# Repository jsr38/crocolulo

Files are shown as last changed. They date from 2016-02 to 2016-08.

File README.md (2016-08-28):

# crocolulo
Alligator Board expansion for >= 3A stepper motors

This repository contains hardware designs for an Alligator expansion board that replaces the Piggy.

My CoreXY 3D printer [savagecorexy](https://github.com/jsr38/savagecorexy) is currently fitted with Alligator Board electronics.  This expansion board allows an Alligator Board to neatly interface with 6 external high current stepper drivers as well as bring out analogue IO pins to a header for experimentation or further customisation.

crocolulo:
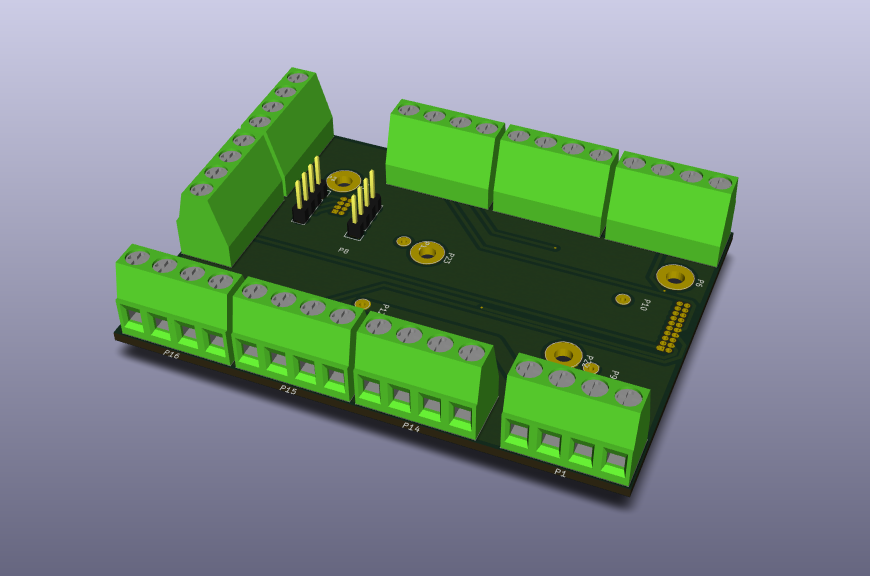
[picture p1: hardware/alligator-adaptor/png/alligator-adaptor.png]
Crocolulo Alligator Expansion


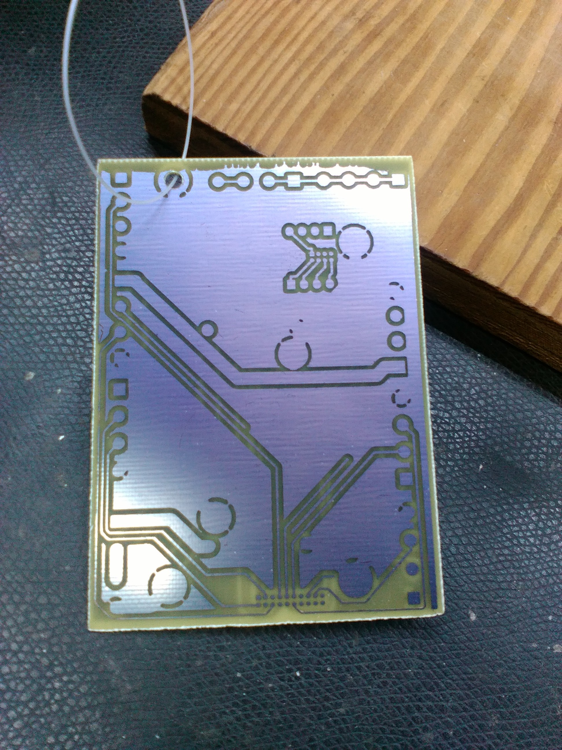
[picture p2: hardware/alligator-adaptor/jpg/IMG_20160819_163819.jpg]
One side of prototype PCB


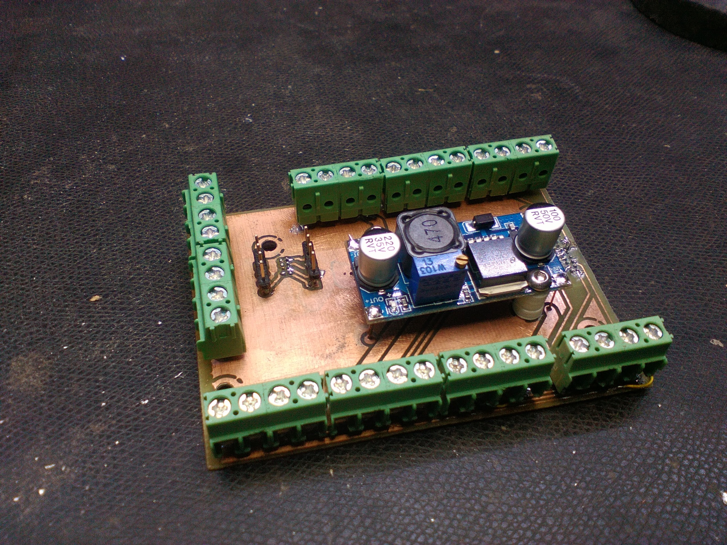
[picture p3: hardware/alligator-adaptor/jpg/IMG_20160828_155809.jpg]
Prototype version 0.1


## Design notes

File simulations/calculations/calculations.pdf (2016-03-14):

# 3D printer calculations

### Jeremy Reeve

Independent Researcher,
jeremy.reeve81@gmail.com

### March 14, 2016

## 1 Belt calculations

For an endless belt, what is the circumference required to fit two pullies, radii r1, r2 and separation, d?

l = π (r1 + r2) + 2q
s

2 + (r2 − r1)

2
(1)

Steps per millimeter of travel in the X direction:

## 2 Stepper motor calculations

Step frequency for 200 mms

−1
: 200 steps / 72mm pulley circumference step frequency 200 * 200 / 72 = 555.56 steps s

−1

1
f = 1.8ms
Waveform rise and fall times were taken from the IR2184 MOSFET High and Low Side driver datasheet.
For our gate drivers, per winding of the stepper this means one complete four state cycle per 1.8ms. As can be seen from plots of i(L1), we are only maximally inducing a current of 0.5A to flow, which means we have factor 2.8/0.5 = 5.6 less torque even at maximum current!!
Try with a slower rate 100mms⁻¹
As can be seen, with a 50% duty cycle, to allow for the other phase of the stepper winding, this is still less than 1.0A which is 1/3 of the rated torque. All the current waveforms seem to exhibit a bias toward -ve which increases with pulse length. Note that if the waveforms are reversed in time, reversing the order of the pulses, the -ve bias is now a +ve bias.

1

## 3 MOSFET notes

Saturation mode when:

VGSVthVDS ≥ (VGSVth)

Our IRL2203N has VGS(th) = 1.0V @ 1V VDS

VGSVth

and VDS ≥ (VGSVth) →
Look like we are limited by v(t) = L

di
dt.

2

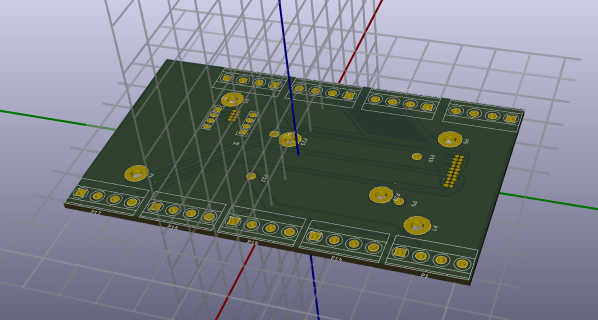
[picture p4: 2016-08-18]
hardware/alligator-adaptor/png/3d-view.png

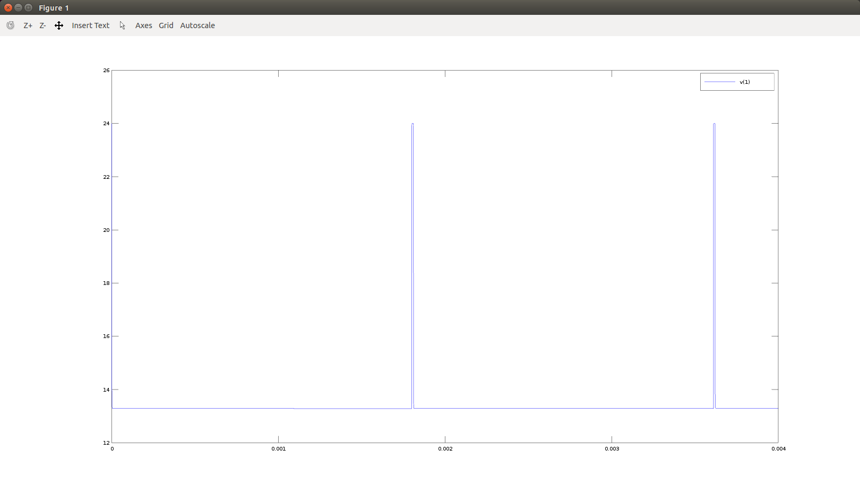
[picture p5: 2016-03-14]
simulations/fig/v_node_1.png

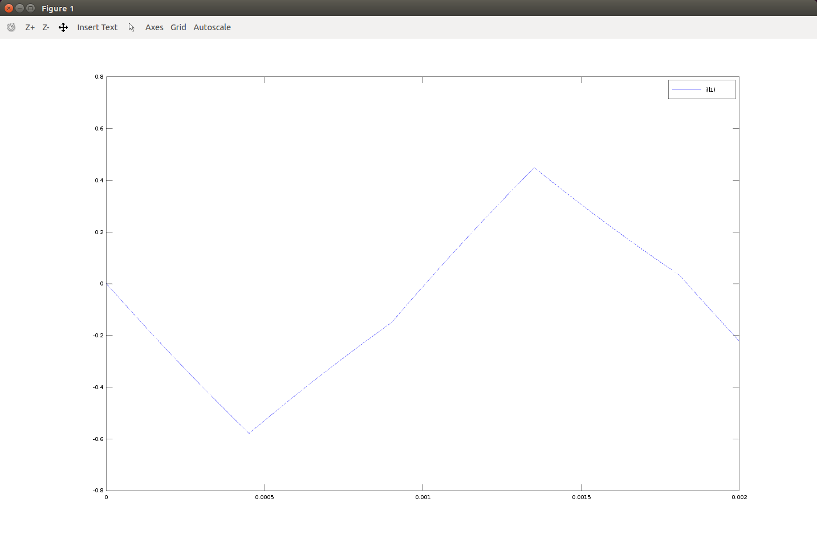
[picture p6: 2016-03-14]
simulations/fig/i_l1.png

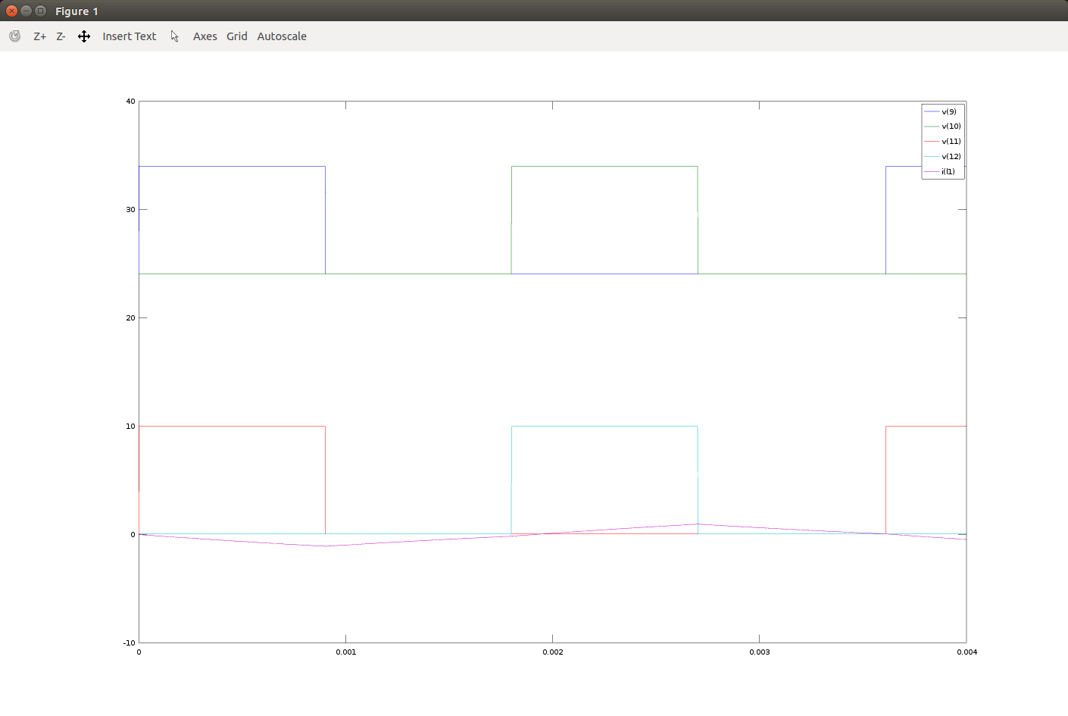
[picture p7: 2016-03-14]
simulations/fig/v_i_l1_0.5_3.6.png

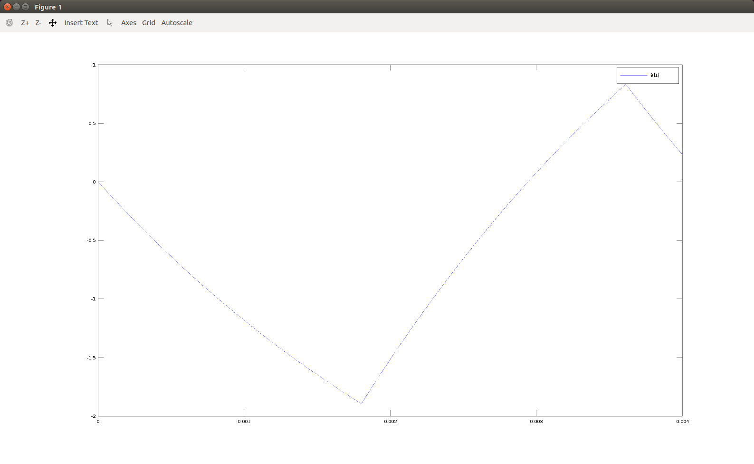
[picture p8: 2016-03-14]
simulations/fig/l1_1.0_3.6m.png

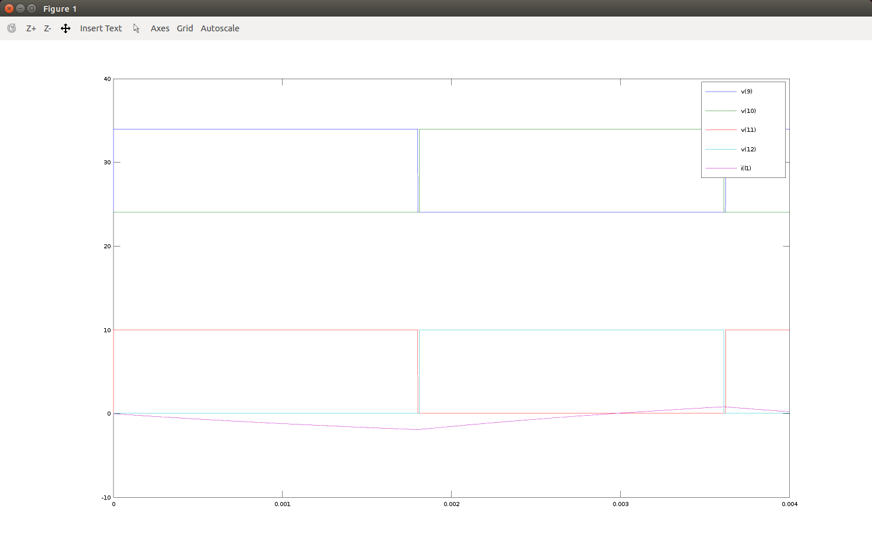
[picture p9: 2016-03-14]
simulations/fig/v_i_l1_1.0_3.6m.png

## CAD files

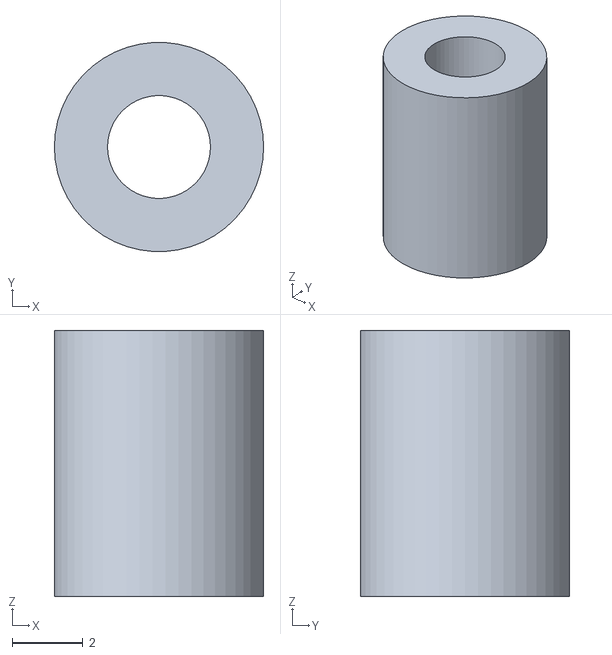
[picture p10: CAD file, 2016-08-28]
hardware/stl/smps-stand-off.stl
5.90 x 5.89 x 7.50

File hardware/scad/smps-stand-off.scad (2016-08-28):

$fn = 50;

difference() {
    cylinder(r = 2.95, h = 7.5);
    cylinder(r = 1.45, h = 7.5);
}

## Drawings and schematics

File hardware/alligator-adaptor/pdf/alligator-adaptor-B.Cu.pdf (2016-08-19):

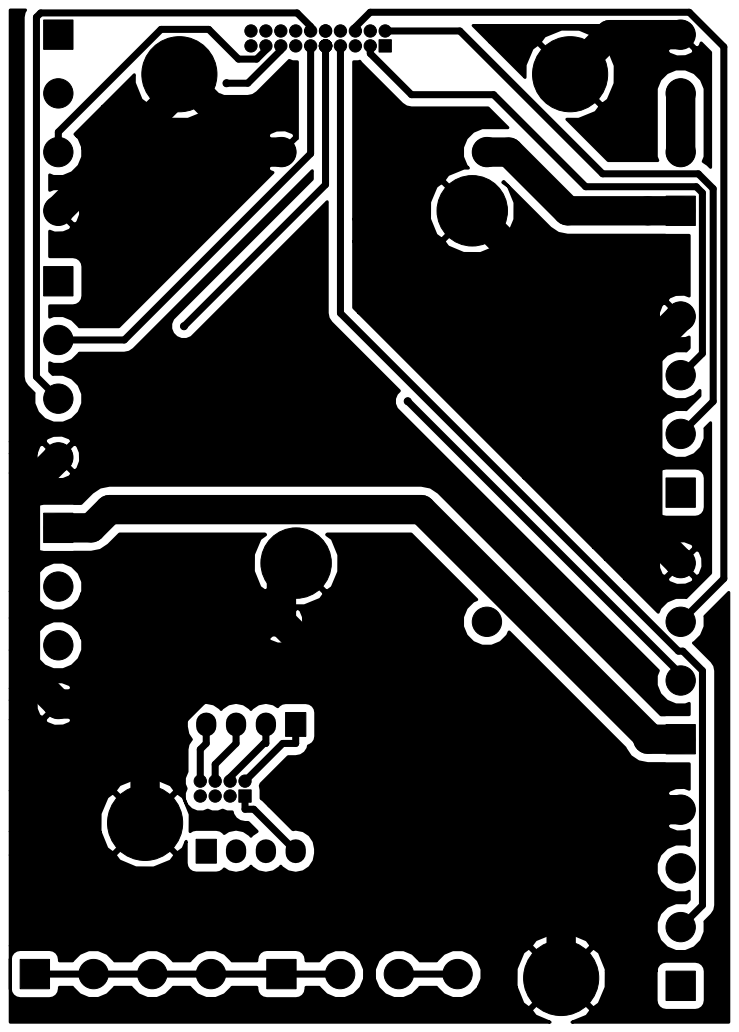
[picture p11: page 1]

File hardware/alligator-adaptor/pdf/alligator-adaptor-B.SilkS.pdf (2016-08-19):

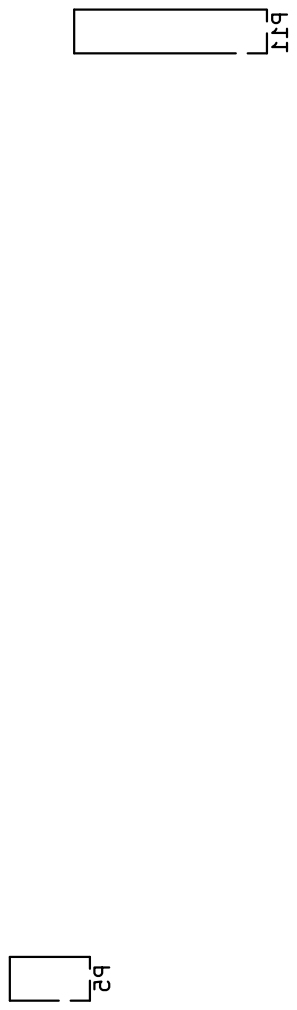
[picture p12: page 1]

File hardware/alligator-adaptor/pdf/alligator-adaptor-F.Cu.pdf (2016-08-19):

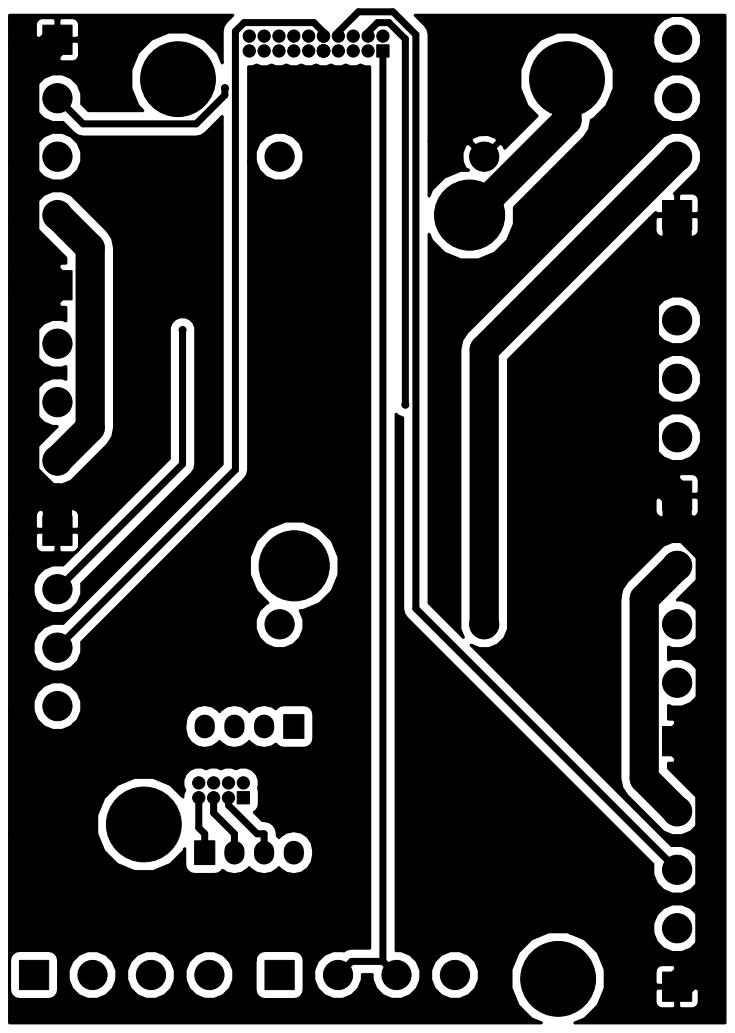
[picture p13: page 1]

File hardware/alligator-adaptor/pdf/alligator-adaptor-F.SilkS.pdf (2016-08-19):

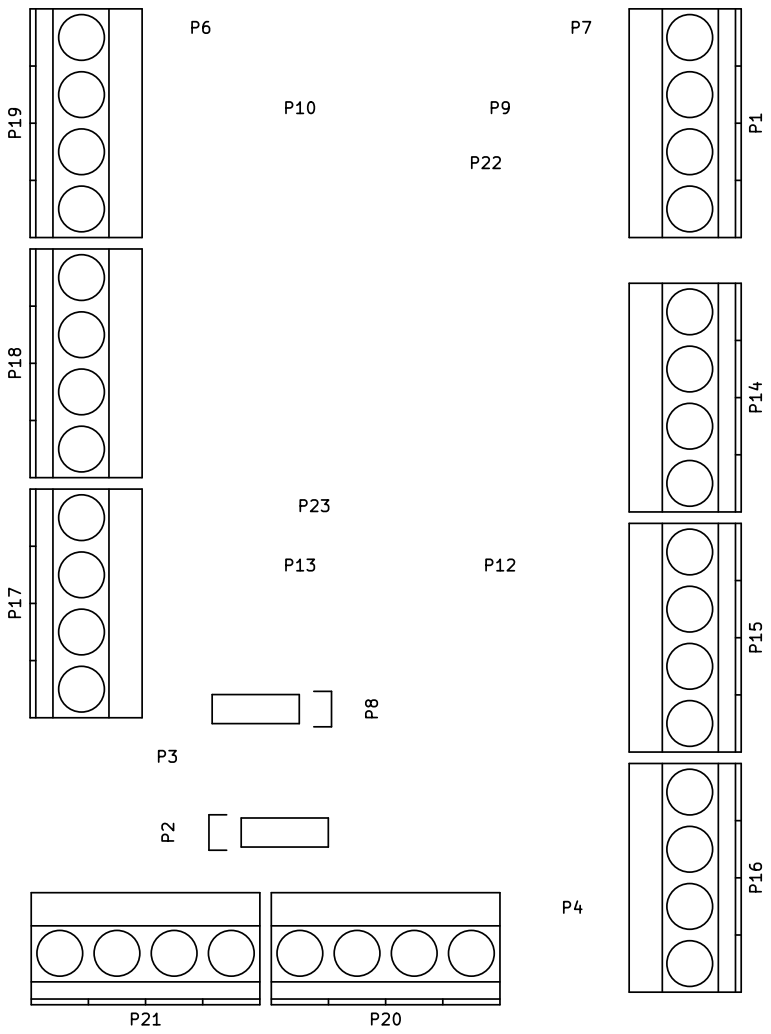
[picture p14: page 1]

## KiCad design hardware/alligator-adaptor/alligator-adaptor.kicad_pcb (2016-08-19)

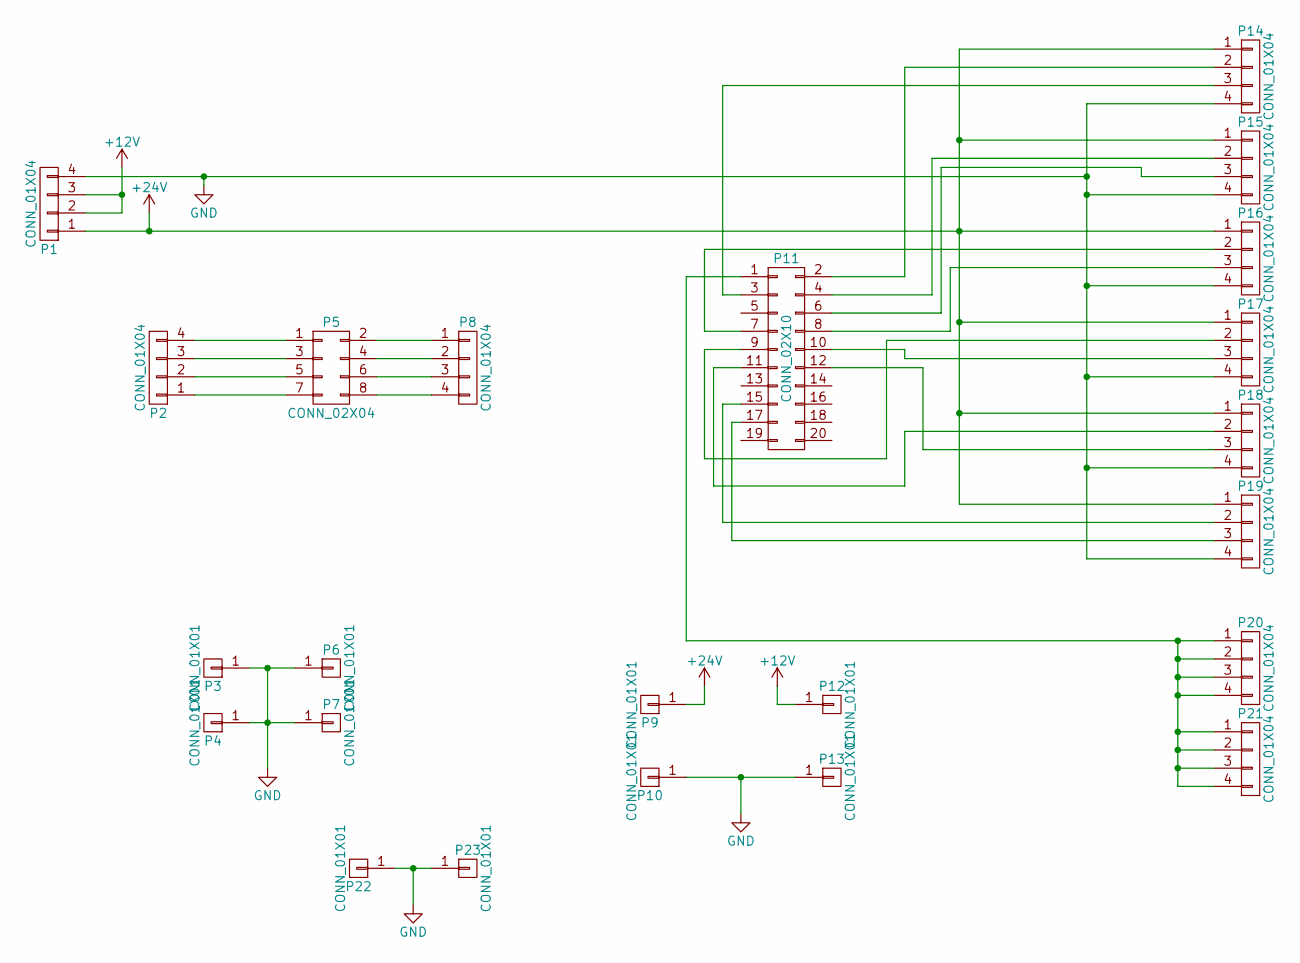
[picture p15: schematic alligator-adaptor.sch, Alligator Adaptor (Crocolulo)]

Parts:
P1, P14, P15, P16, P17, P18, P19, P20, P21: CONN_01X04; TerminalBlock_Pheonix_MKDS1.5-4pol
P2, P8: CONN_01X04; Pin_Header_Straight_1x04
P3, P4, P6, P7: CONN_01X01; MountingHole_3.2mm_M3_Pad_Via
P5: CONN_02X04; Pin_Header_Straight_2x04_Pitch1.27mm
P9, P10, P12, P13: CONN_01X01; SolderWirePad_single_1mmDrill
P11: CONN_02X10; Pin_Header_Straight_2x10_Pitch1.27mm
P22, P23: CONN_01X01; MountingHole_3mm_Pad_Via

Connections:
+12V: P1.2, P1.3, P12.1
+24V: P1.1, P9.1, P14.1, P15.1, P16.1, P17.1, P18.1, P19.1
GND: P1.4, P3.1, P4.1, P6.1, P7.1, P10.1, P13.1, P14.4, P15.4, P16.4, P17.4, P18.4, P19.4, P22.1, P23.1
unnamed: P2.1, P5.7
unnamed: P2.2, P5.5
unnamed: P2.3, P5.3
unnamed: P2.4, P5.1
unnamed: P5.2, P8.1
unnamed: P5.4, P8.2
unnamed: P5.6, P8.3
unnamed: P5.8, P8.4
unnamed: P11.1, P20.1, P20.2, P20.3, P20.4, P21.1, P21.2, P21.3, P21.4
unnamed: P11.2, P14.2
unnamed: P11.3, P14.3
unnamed: P11.4, P15.2
unnamed: P11.6, P15.3
unnamed: P11.7, P16.2
unnamed: P11.8, P16.3
unnamed: P11.9, P17.2
unnamed: P11.10, P17.3
unnamed: P11.11, P18.2
unnamed: P11.12, P18.3
unnamed: P11.15, P19.2
unnamed: P11.17, P19.3

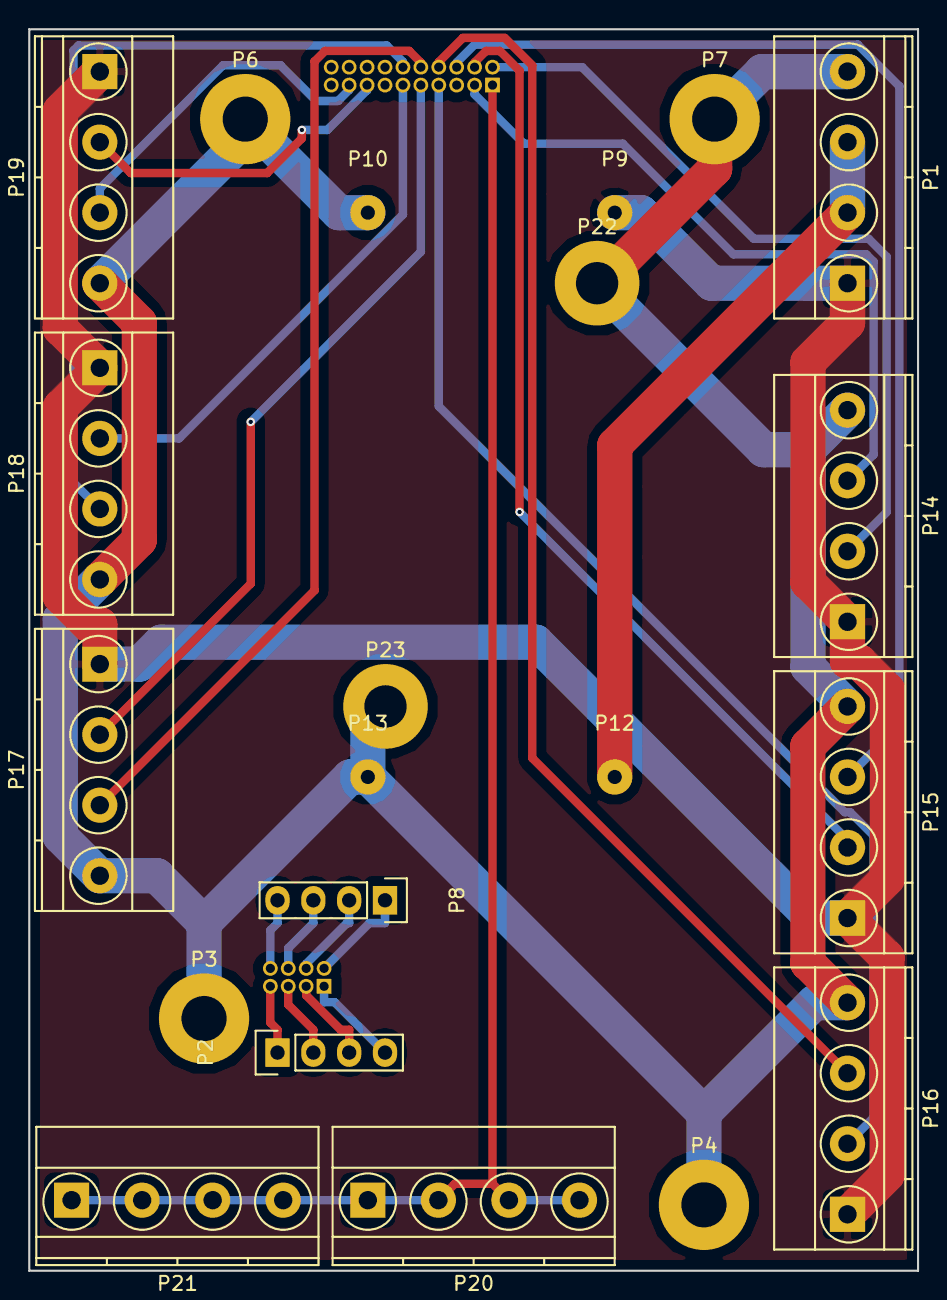
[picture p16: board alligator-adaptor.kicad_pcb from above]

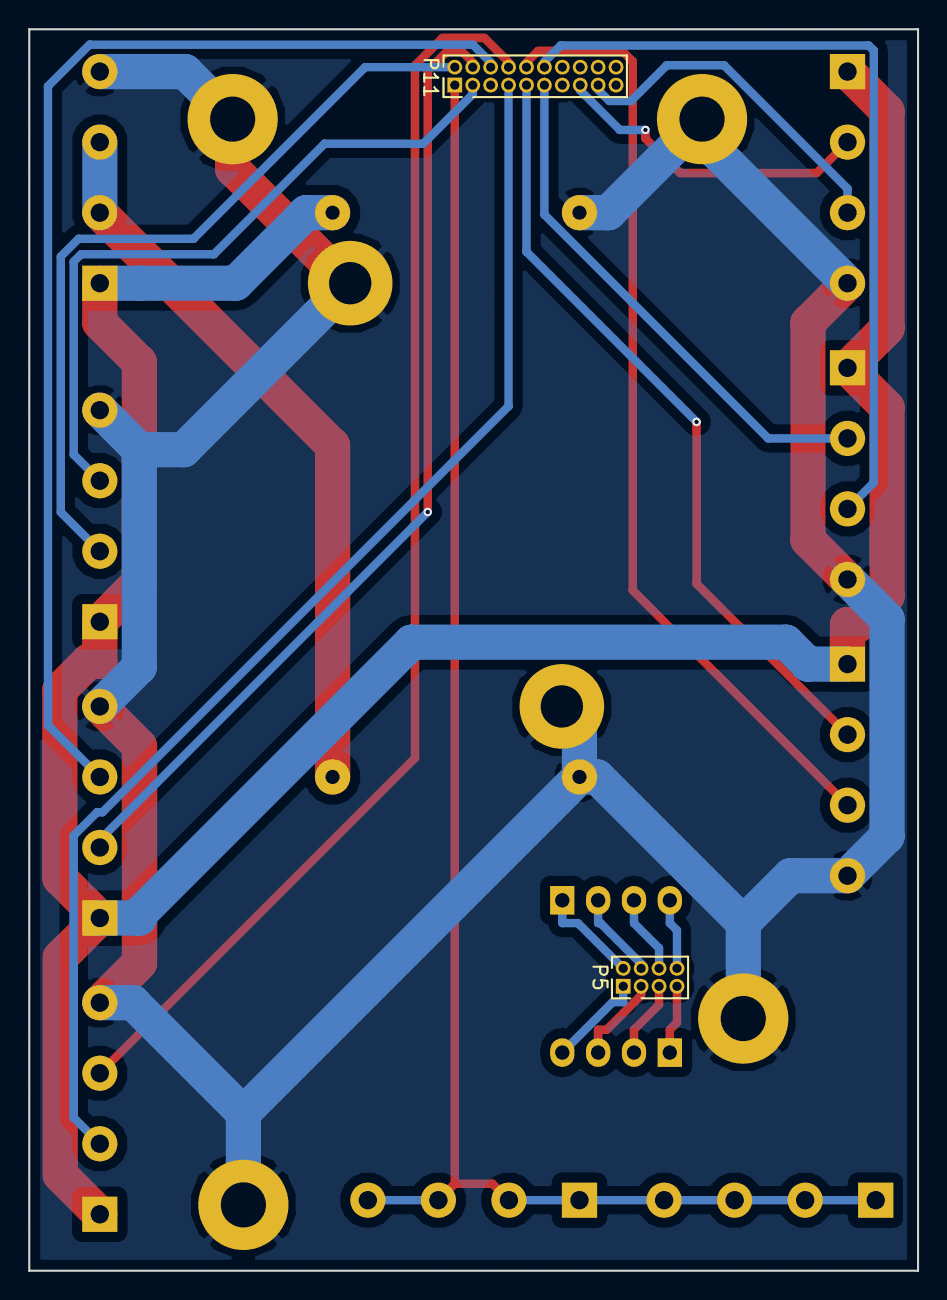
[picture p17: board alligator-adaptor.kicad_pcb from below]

Board: 2 copper layers, 63.0 x 88.0 mm, 23 parts (2 on the bottom side), 24 nets.

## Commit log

2016-02-21 Add sub sheet to describe a single stepper driver module
    [crocolulo.sch, stepper-driver-n.sch]
2016-02-21 Add more sub sheets
    [crocolulo.sch, stepper-driver-1.sch, stepper-driver-2.sch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]
2016-03-09 h-bridge simulation WIP;
    [h-bridge.sch]
2016-03-10 First pass at transient simulation. Broken!
    [h-bridge.sch]
2016-03-11 Include some non-zero resistance between pure voltage source and gate. Add some broken scripts intended to load spice output into Octave structures.
    [h-bridge.sch]
2016-03-12 OOops. Remove octave workspace.
    [h-bridge.sch]
2016-03-14 Add figures for intial exploration. Begin driver simulation.
    [h-bridge_ic_driver.sch, h-bridge_vemf.sch]
2016-05-03 Add PWM versions of simulations and pin descriptions of Pandaboard expansion ports
    [h-bridge_pwm.sch]
2016-08-09 Reorganise hardware dir. Update calcs document. Add datasheets. First cut of Alligator adaptor schematic. Record expansion IOs for reference.
    [alligator-adaptor.kicad_pcb, alligator-adaptor.sch, crocolulo.kicad_pcb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]
2016-08-11 First pass at component footprint association.
    [alligator-adaptor.sch]
2016-08-18 First pass at footprint selection and layout.
    [alligator-adaptor.sch]
2016-08-18 First cut. Routed, zone filled. Plots generated.
    [alligator-adaptor.dsn, alligator-adaptor.kicad_pcb, alligator-adaptor.sch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]
2016-08-18 Add 3D view of board model.
2016-08-19 Relocate pin headers for Alligator Board. Relocate stepper enable connectors to be furthest from the connector and reduce overall size of board.
    [alligator-adaptor.dsn, alligator-adaptor.kicad_pcb]
2016-08-28 Add a plastic stand-off and some prototype photos
    [smps-stand-off.scad, smps-stand-off.stl]
